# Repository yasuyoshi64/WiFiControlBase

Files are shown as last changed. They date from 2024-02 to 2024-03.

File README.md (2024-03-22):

# sdkconfig
Serial flasher config

	Flash size				4MB

Partition Table

	Patition Table			Single factory app (large), no OTA

WiFiControlBase

	LED GPIO number			5

SD card PIN configuration

	MOSI GPIO number		17
	MOSO GPIO number		19
	CLK GPIO number			18
	CS GPIO number			16
	SD card sw GPIO number	4

OLED(SSD1306) PIN configuration

	I2C SDA GPIO number		21
	I2C SCL GPIO number		22

HTTP Server

	WebSocket server support	TRUE

FAT Filesystem support

	Long filename support	Long filename buffer in heap
	OEM Code Page			Japanese (DBCS) (CP932)

Color settings

	Color depth.			1: 1 byte per pixel

Font usage

Enable built-in fonts

	Enable UNSCII 8 (Perfect monospace font)	TRUE

3rd Party Libraries

	QR code library			TRUE

# 機能

## SDカードの内容

### ./config

```
ssid=[Wi-Fi SSID]
pass=[Wi-Fi Password]
```

### ./document

ここにはWeb用のファイルを格納します。

## 使い方

* 「No file」と表示されている場合はSDカードを挿入します。
* 「Wi-Fi Connecting」はWi-Fi接続中です。
* Wi-Fi接続完了後はQRコードが表示されます。QRコードを読み込むとWebのURLが読み込まれ、documentのWebが表示されます。
* QRコードは30秒で消灯します。GPIO0のボタンを押下すると再度30秒表示されます。
* SDカードは電源ON中でも抜き差し可能です。

## 回路図

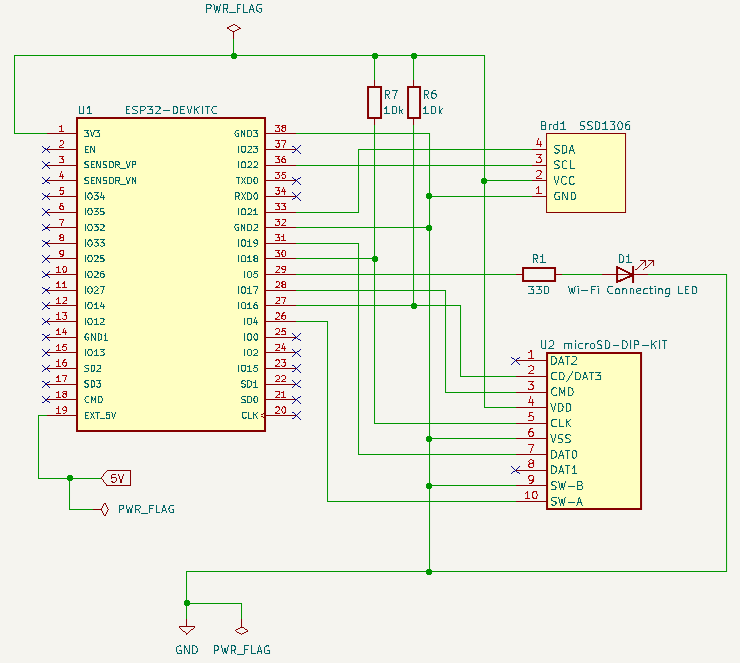
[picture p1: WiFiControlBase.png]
回路図


## Web画面

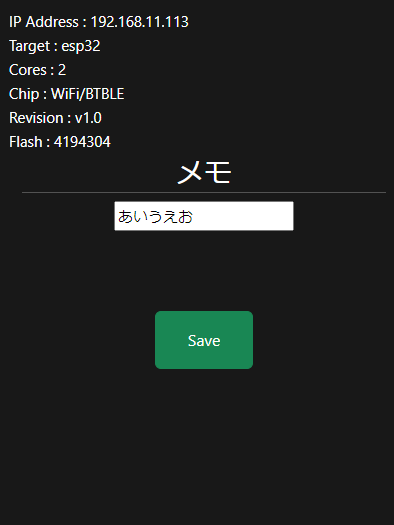
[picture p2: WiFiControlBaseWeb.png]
Web画面


ロード時にIPアドレスやチップ情報などを読み込み。
メモを入力してSaveボタンをクリックするとSDカードのsaveファイルに格納されます。
メモは再ロード時に読み込まれます。

# _Sample project_

(See the README.md file in the upper level 'examples' directory for more information about examples.)

This is the simplest buildable example. The example is used by command `idf.py create-project`
that copies the project to user specified path and set it's name. For more information follow the [docs page](https://docs.espressif.com/projects/esp-idf/en/latest/api-guides/build-system.html#start-a-new-project)

## How to use example
We encourage the users to use the example as a template for the new projects.
A recommended way is to follow the instructions on a [docs page](https://docs.espressif.com/projects/esp-idf/en/latest/api-guides/build-system.html#start-a-new-project).

## Example folder contents

The project **sample_project** contains one source file in C language [main.c](main/main.c). The file is located in folder [main](main).

ESP-IDF projects are built using CMake. The project build configuration is contained in `CMakeLists.txt`
files that provide set of directives and instructions describing the project's source files and targets
(executable, library, or both). 

Below is short explanation of remaining files in the project folder.

```
├── CMakeLists.txt
├── main
│   ├── CMakeLists.txt
│   └── main.c
└── README.md                  This is the file you are currently reading
```
Additionally, the sample project contains Makefile and component.mk files, used for the legacy Make based build system. 
They are not used or needed when building with CMake and idf.py.

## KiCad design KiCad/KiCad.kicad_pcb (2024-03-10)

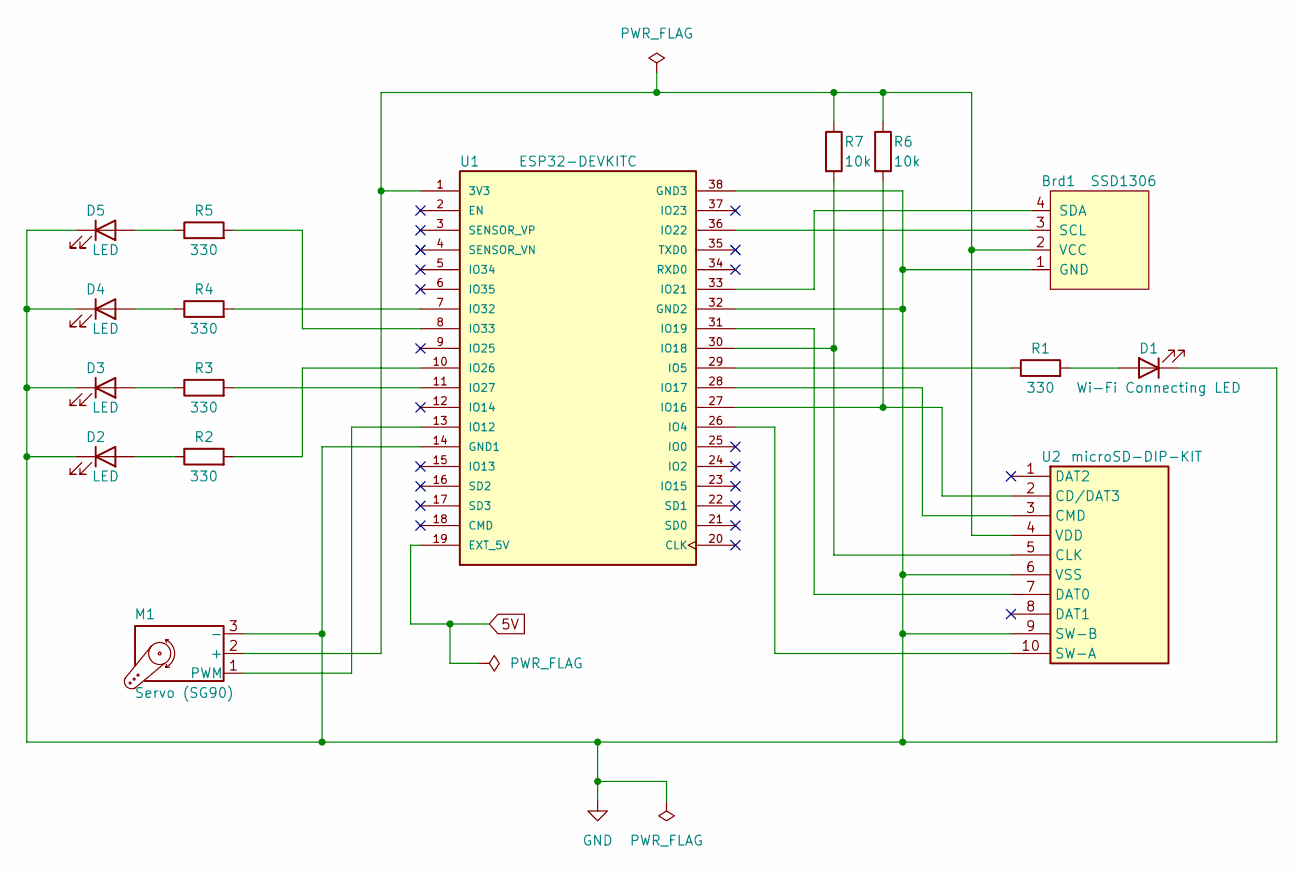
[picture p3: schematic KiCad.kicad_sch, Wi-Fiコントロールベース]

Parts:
Brd1: SSD1306; 128x64OLED
D1: Wi-Fi Connecting LED; LED_D5.0mm
D2, D3, D4, D5: LED; LED_D5.0mm
M1: Servo (SG90); PinHeader_1x03_P2.54mm_Horizontal
R1, R2, R3, R4, R5: 330; R_Axial_DIN0204_L3.6mm_D1.6mm_P5.08mm_Horizontal
R6, R7: 10k; R_Axial_DIN0204_L3.6mm_D1.6mm_P5.08mm_Horizontal
U1: ESP32-DEVKITC; MODULE_ESP32-DEVKITC; PARTREV N/A
U2: microSD-DIP-KIT; microSD-DIP-Kit

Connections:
+3.3V: Brd1.2 (VCC), M1.2 (+), R6.1, R7.1, U1.1 (3V3), U2.4 (VDD)
GND: Brd1.1 (GND), D1.1 (K), D2.1 (K), D3.1 (K), D4.1 (K), D5.1 (K), M1.3 (-), U1.14 (GND1), U1.32 (GND2), U1.38 (GND3), U2.6 (VSS), U2.9 (SW-B)
unnamed: Brd1.3 (SCL), U1.36 (IO22)
unnamed: Brd1.4 (SDA), U1.33 (IO21)
unnamed: D1.2 (A), R1.2
unnamed: D2.2 (A), R2.1
unnamed: D3.2 (A), R3.1
unnamed: D4.2 (A), R4.1
unnamed: D5.2 (A), R5.1
unnamed: M1.1 (PWM), U1.13 (IO12)
unnamed: U1.26 (IO4), U2.10 (SW-A)
unnamed: R1.1, U1.29 (IO5)
unnamed: R6.2, U1.27 (IO16), U2.2 (CD/DAT3)
unnamed: U1.28 (IO17), U2.3 (CMD)
unnamed: R7.2, U1.30 (IO18), U2.5 (CLK)
unnamed: U1.31 (IO19), U2.7 (DAT0)
unnamed: R2.2, U1.10 (IO26)
unnamed: R3.2, U1.11 (IO27)
unnamed: R4.2, U1.7 (IO32)
unnamed: R5.2, U1.8 (IO33)

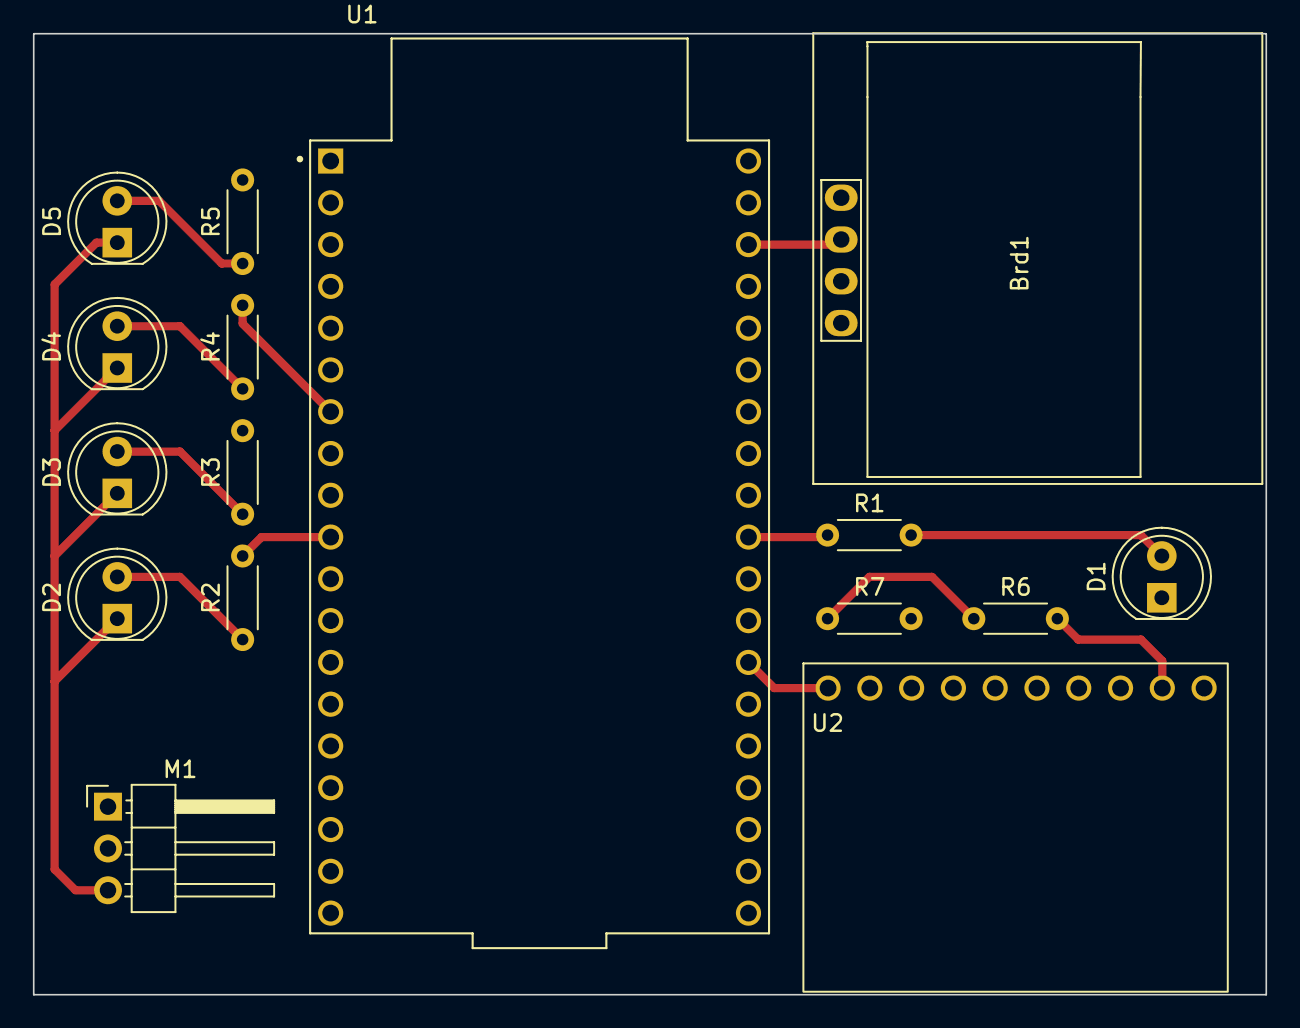
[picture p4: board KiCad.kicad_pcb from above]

Board: 2 copper layers, 74.9 x 58.4 mm, 16 parts (0 on the bottom side), 20 nets.

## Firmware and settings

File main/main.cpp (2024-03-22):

#include <stdio.h>
#include <sys/types.h>
#include <dirent.h>
#include <errno.h>
#include <string.h>
#include <iostream>
#include <map>
#include "freertos/FreeRTOS.h"
#include "freertos/task.h"
#include "freertos/queue.h"
#include "freertos/timers.h"
#include "nvs_flash.h"
#include "driver/gpio.h"
#include "esp_http_server.h"
#include "cJSON.h"
#include "esp_chip_info.h"
#include "esp_flash.h"
#include "esp_log.h"

#include "main.hpp"

#define TAG "Application"
#define ROOT "/mnt"

Application app;

// メッセージ種別 (メッセージキュー用)
enum class AppMessage {
    UpdateDisplay,      // ディスプレイに現在状態表示
    WIFIConnection,     // Wi-Fi接続
    WIFIDisconnection,  // Wi-Fi切断
    Quit                // 終了
};

Application::Application() {
    m_LedState = false;
    m_xHandle = NULL;
    m_xQueue = NULL;
    m_isWiFi = false;
    m_30sec_off = false;
}

// 初期化
void Application::init() {
    ESP_LOGI(TAG, "Init(S)");

    // LED初期化
    gpio_reset_pin((gpio_num_t)CONFIG_LED_PIN);
    gpio_set_direction((gpio_num_t)CONFIG_LED_PIN, GPIO_MODE_OUTPUT);
    led(0);

    // ボタン初期化(GPIO0)
    gpio_reset_pin((gpio_num_t)0);
    gpio_set_intr_type((gpio_num_t)0, GPIO_INTR_NEGEDGE);
    gpio_set_direction((gpio_num_t)0, GPIO_MODE_INPUT);
    gpio_pulldown_dis((gpio_num_t)0);
    gpio_pullup_en((gpio_num_t)0);
    gpio_install_isr_service(0);
    gpio_isr_handler_add((gpio_num_t)0, btn0HandlerFunc, (void*)this);

    // タスク作成
    xTaskCreate(Application::app_task, TAG, configMINIMAL_STACK_SIZE * 2, (void*)this, tskIDLE_PRIORITY, &m_xHandle);

    // メッセージキューの初期化
    m_xQueue = xQueueCreate(10, sizeof(AppMessage));

    // SDカード初期化
    m_sd_card.init(ROOT);
    m_sd_card.setMountCallback(mountFunc, this);

    // 保存データ初期化
    m_save_data.init(ROOT);

    // OLED(SSD1306)ディスプレイ初期化
    m_oled.init(dispInitCompFunc, this);

    // Wi-Fi初期化
    m_wifi.init(wifiConnectFunc, this);

    // Webサーバー初期化
    m_web.init();
    m_web.addHandler(HTTP_GET, "get_data", getData, this);
    m_web.addHandler(HTTP_POST, "set_data", setData, this);
    m_web.addHandler(HTTP_POST, "save", save, this);
    m_web.setWebSocketHandler(sebSocketFunc, this);

    ESP_LOGI(TAG, "Init(E)");
}

// タスク
void Application::app_task(void* arg) {
    Application* pThis = (Application*)arg;
    AppMessage msg;
    bool loop = true;
    while(loop) {
        // メッセージキュー読み取り
        if (pThis->m_xQueue != NULL && xQueueReceive(pThis->m_xQueue, (void*)&msg, portMAX_DELAY) == pdTRUE) {
            switch(msg) {
                case AppMessage::UpdateDisplay:     // ディスプレイに現在状態表示
                    pThis->updateDisplay();
                    break;
                case AppMessage::WIFIConnection:    // Wi-Fi接続
                    pThis->wifiConnection();
                    break;
                case AppMessage::WIFIDisconnection: // Wi-Fi切断
                    pThis->wifiDisconnection();
                    break;
                case AppMessage::Quit:              // 終了
                    loop = false;
                    break;
            }
        }
    }
    // 終了処理
    vTaskDelete(NULL);
}

// LED点灯制御
//  state   : 1=点灯, 0=消灯
void Application::led(int state) {
    m_LedState = state;
    gpio_set_level((gpio_num_t)CONFIG_LED_PIN, m_LedState);
}

// SDカードマウントコールバック
void Application::mountFunc(bool isMount, void* context) {
    ESP_LOGI(TAG, "SD Card mount : %d", isMount);
    Application* pThis = (Application*)context;
    AppMessage msg = AppMessage::UpdateDisplay;
    xQueueSend(pThis->m_xQueue, &msg, portMAX_DELAY);
    if (isMount && pThis->getConfig(ROOT)) {
        AppMessage msg = AppMessage::WIFIConnection;
        xQueueSend(pThis->m_xQueue, &msg, portMAX_DELAY);
    } else {
        AppMessage msg = AppMessage::WIFIDisconnection;
        xQueueSend(pThis->m_xQueue, &msg, portMAX_DELAY);
    }
    // 保存データ読み込み
    pThis->m_save_data.read();
}

// ファイル一覧コールバック
bool Application::fileFunc(bool isFile, const char* name, void* context) {
    Application* pThis = (Application*)context;
    ESP_LOGI(TAG, "%s : %s", isFile ? "File" : "Directory", name);
    return true;
}

// ディスプレイ初期化完了コールバック
void Application::dispInitCompFunc(void* context) {
    Application* pThis = (Application*)context;
    AppMessage msg = AppMessage::UpdateDisplay;
    xQueueSend(pThis->m_xQueue, &msg, portMAX_DELAY);
}

// Wi-Fi接続コールバック
void Application::wifiConnectFunc(bool isConnect, void* context) {
    Application* pThis = (Application*)context;
    if (isConnect) {
        pThis->m_30sec_off = pThis->m_isWiFi = true;
        const char* ipAddress = pThis->m_wifi.getIPAddress();
        ESP_LOGI(TAG, "IP Address: %s", ipAddress);
        pThis->led(0);
        pThis->m_web.start(ipAddress, ROOT);   // Webサーバー開始

        // 30秒後に画面を消灯するためにタイマ設定
        pThis->timer30secStart();

        // pThis->m_sd_card.fileLists("/document/", fileFunc, pThis);
    } else {
        pThis->m_30sec_off = pThis->m_isWiFi = false;
    }
    AppMessage msg = AppMessage::UpdateDisplay;
    xQueueSend(pThis->m_xQueue, &msg, portMAX_DELAY);
}

// 30秒タイマ開始
void Application::timer30secStart() {
    TimerHandle_t xTimer = xTimerCreate(
        "30SecTimer",
        pdMS_TO_TICKS(30000),
        pdFALSE,
        this,
        timer30secFunc
    );
    if (xTimer != NULL)
        xTimerStart(xTimer, 0);
}

// 30秒タイマ
void Application::timer30secFunc(TimerHandle_t xTimer) {
    Application* pThis = (Application*)pvTimerGetTimerID(xTimer);
    if (pThis->m_30sec_off == true) {
        pThis->m_30sec_off = false;
        AppMessage msg = AppMessage::UpdateDisplay;
        xQueueSend(pThis->m_xQueue, &msg, portMAX_DELAY);
    }
}

// 基盤上のボタン押下ハンドラ (GPIO0)
void IRAM_ATTR Application::btn0HandlerFunc(void* context) {
    Application* pThis = (Application*)context;
    pThis->m_30sec_off = true;
    pThis->timer30secStart();
    AppMessage msg = AppMessage::UpdateDisplay;
    xQueueSend(pThis->m_xQueue, &msg, portMAX_DELAY);
}

// ディスプレイに現在状態表示
void Application::updateDisplay() {
    if (!m_oled.isInitialize())
        return;
    if (m_isWiFi) {
        if (m_30sec_off) {
            const char* ipAddress = m_wifi.getIPAddress();
            char url[256];
            sprintf(url, "http://%s/", ipAddress);
            m_oled.dispQRCode(url);
        } else {
            // 画面消灯
            m_oled.dispClear();
        }
    } else if (m_sd_card.isMount()) {
        m_oled.dispString("Wi-Fi Connecting");
        led(1);
    } else {
        m_oled.dispString("No File");
        led(0);
    }
}

// Wi-Fi接続
void Application::wifiConnection() {
    wifiDisconnection();
    if (m_configMap.find("ssid") == m_configMap.end() || m_configMap.find("pass") == m_configMap.end())
        return; // CONFIGファイルにssidまたはpassの設定がない
    const char* ssid = m_configMap["ssid"].c_str();
    const char* pass = m_configMap["pass"].c_str();
    m_wifi.connect(ssid, pass);
}

// Wi-Fi切断
void Application::wifiDisconnection() {
    m_web.stop();
    m_wifi.disconnect();
}

// WebAPI GET /API/get_data
// {
//   "ip_address": "192.168.0.1",
//   "target": "ESP32",
//   "cores": 2,
//   "chip": "WiFi/BT",
//   "revision": "v1.1"
//   "flash": 4,
//   "memo": "abcdefg"
// }
void Application::getData(httpd_req_t *req, void* context) {
    ESP_LOGI(TAG, "getData");
    Application* pThis = (Application*)context;
    char resp[256];
    const char* ip_address = pThis->m_wifi.getIPAddress();
    ip_address = ip_address == NULL ? "" : ip_address;
    esp_chip_info_t chip_info;
    esp_chip_info(&chip_info);
    unsigned major_rev = chip_info.revision / 100;
    unsigned minor_rev = chip_info.revision % 100;
    uint32_t flash_size;
    esp_flash_get_size(NULL, &flash_size);
    const char* memo = pThis->m_save_data.get("memo");
    memo = memo == NULL ? "" : memo;
    std::string format = R"({
        "ip_address": "%s",
        "target": "%s",
        "cores": %d,
        "chip": "%s%s%s%s",
        "revision": "v%d.%d",
        "flash": %d,
        "memo": "%s"
    })";
    sprintf(resp, format.c_str(), 
        ip_address,
        CONFIG_IDF_TARGET,
        chip_info.cores,
        (chip_info.features & CHIP_FEATURE_WIFI_BGN) ? "WiFi/" : "",
        (chip_info.features & CHIP_FEATURE_BT) ? "BT" : "",
        (chip_info.features & CHIP_FEATURE_BLE) ? "BLE" : "",
        (chip_info.features & CHIP_FEATURE_IEEE802154) ? ", 802.15.4 (Zigbee/Thread)" : "",
        major_rev, minor_rev, 
        flash_size,
        memo
    );
    ESP_LOGI(TAG, "%s", resp);
    httpd_resp_set_type(req, "application/json");
    httpd_resp_send(req, resp, strlen(resp));
}

// WebAPI POST /API/set_data
// {
//    memo: "abcdefg"
// }
void Application::setData(httpd_req_t *req, void* context) {
    ESP_LOGI(TAG, "setData");
    Application* pThis = (Application*)context;
    int ret, remaining = req->content_len;
    char body[100];
    if (remaining >= sizeof(body)) {
        ESP_LOGE(TAG, "oversize request body");
        httpd_resp_send_500(req);
        return;
    }
    ret = httpd_req_recv(req, body, remaining);
    if (ret == HTTPD_SOCK_ERR_TIMEOUT) {
        ESP_LOGE(TAG, "timeout");
        httpd_resp_send_408(req);
        return;
    }
    body[ret] = '\0';
    ESP_LOGI(TAG, "body : %s", body);
    cJSON* json = cJSON_Parse(body);
    if (json == NULL) {
        ESP_LOGI(TAG, "json null");
        httpd_resp_send_500(req);
        return;
    }
    cJSON* memo = cJSON_GetObjectItemCaseSensitive(json, "memo");
    if (!cJSON_IsString(memo)) {
        ESP_LOGI(TAG, "json format error");
        httpd_resp_send_500(req);
        return;
    }
    std::string memo_value = cJSON_GetStringValue(memo);
    pThis->m_save_data.set("memo", memo_value.c_str());
    cJSON_Delete(json);
    httpd_resp_send(req, NULL, 0);
}

// WebAPI POST /API/save
void Application::save(httpd_req_t *req, void* context) {
    ESP_LOGI(TAG, "save");
    Application* pThis = (Application*)context;
    pThis->m_save_data.save();
    httpd_resp_send(req, NULL, 0);
}

// WebSocketコールバック
char* Application::sebSocketFunc(const char* data, void* context) {
    return NULL;
}

extern "C" void app_main(void)
{
    nvs_flash_init();     // Flash初期化  (お約束のようなもの)

    app.init();
}

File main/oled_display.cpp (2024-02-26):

/**
 * I2Cに接続されているSSD1306(0.96インチ 128x64 OLEDディスプレイ)のドライブ
 * 
 * 
*/
#include <stdio.h>
#include <string.h>
#include <iostream>
#include "freertos/FreeRTOS.h"
#include "freertos/task.h"
#include "freertos/queue.h"
#include "esp_timer.h"
#include "esp_lcd_panel_io.h"
#include "esp_lcd_panel_ops.h"
#include "driver/i2c.h"
#include "esp_err.h"
#include "esp_log.h"
#include "extra/libs/qrcode/lv_qrcode.h"
#include "oled_display.hpp"

#define TAG "OledDisplay"

#define I2C_HOST        0
#define I2C_HW_ADDR     0x3C
#define I2C_SDA_PIN     CONFIG_SDA_PIN
#define I2C_SCL_PIN     CONFIG_SCL_PIN
#define I2C_OLED_H      128
#define I2C_OLED_V      64

// メッセージ種別 (メッセージキュー用)
enum class OledDisplayMessage {
    Init,       // 画面初期処理
    Clear,      // 画面消去
    On,         // 画面On
    Off,        // 画面Off
    QRCode,     // QRコード表示
    String,     // 文字列表示
    Quit        // 終了
};

OledDisplay::OledDisplay() {
    clear();
}

void OledDisplay::clear() {
    m_funcInitilizationComplettion = NULL;
    m_hDisp = NULL;
    m_panel_handle = NULL;
    m_xHandle = NULL;
    m_xQueue = NULL;
    m_text = "";
}

void OledDisplay::init(CallbackInitializationCompletionFunction func, void* context) {
    ESP_LOGI(TAG, "Init(S)");

    m_funcInitilizationComplettion = func;
    m_funcInitilizationComplettionContext = context;

    // タスク作成
    xTaskCreate(OledDisplay::task, TAG, configMINIMAL_STACK_SIZE * 3, (void*)this, tskIDLE_PRIORITY, &m_xHandle);

    // メッセージキューの初期化
    m_xQueue = xQueueCreate(10, sizeof(OledDisplayMessage));

    // 初期化用メッセージポスト
    OledDisplayMessage msg = OledDisplayMessage::Init;
    xQueueSend(m_xQueue, &msg, portMAX_DELAY);

   ESP_LOGI(TAG, "Init(E)");
}

// タスク
void OledDisplay::task(void* arg) {
    OledDisplay* pThis = (OledDisplay*)arg;
    OledDisplayMessage msg;
    bool loop = true;
    while(loop) {
        // メッセージキュー読み取り
        if (pThis->m_xQueue != NULL && xQueueReceive(pThis->m_xQueue, (void*)&msg, portMAX_DELAY) == pdTRUE) {
            switch(msg) {
                case OledDisplayMessage::Init:      // 画面初期化処理
                    pThis->initDisplay();
                    break;
                case OledDisplayMessage::Clear:     // 画面消去
                    lv_obj_clean(lv_scr_act());
                    break;
                case OledDisplayMessage::On:        // 画面On
                    esp_lcd_panel_disp_on_off(pThis->m_panel_handle, true);     // LCDのON/OFF  ONにする
                    break;
                case OledDisplayMessage::Off:       // 画面Off
                    esp_lcd_panel_disp_on_off(pThis->m_panel_handle, false);    // LCDのON/OFF  OFFにする
                    break;
                case OledDisplayMessage::QRCode:    // QRコード表示
                    {
                        lv_obj_t* active_screen = lv_scr_act();
                        lv_obj_clean(active_screen);
                        lv_obj_t *qr = lv_qrcode_create(active_screen, 64, lv_color_hex3(0xFF), lv_color_hex3(0x00));
                        lv_qrcode_update(qr, pThis->m_text.c_str(), pThis->m_text.size());
                        lv_obj_center(qr);
                    }
                    break;
                case OledDisplayMessage::String:    // 文字列表示
                    {
                        lv_obj_t* active_screen = lv_scr_act();
                        lv_obj_clean(active_screen);
                        lv_obj_t *label = lv_label_create(active_screen);
                        lv_label_set_text(label, pThis->m_text.c_str());
                        lv_obj_center(label);
                    }
                    break;
                case OledDisplayMessage::Quit:      // 終了
                    loop = false;
                    break;
            }
        }
    }
    // 終了処理
    pThis->clear();
    vTaskDelete(NULL);
}

// 表示内容をクリア
void OledDisplay::dispClear() {
    ESP_LOGI(TAG, "dispClear");
    OledDisplayMessage msg = OledDisplayMessage::Clear;
    xQueueSend(m_xQueue, &msg, portMAX_DELAY);
}

// ディスプレイON
void OledDisplay::dispOn() {
    ESP_LOGI(TAG, "dispOn");
    OledDisplayMessage msg = OledDisplayMessage::On;
    xQueueSend(m_xQueue, &msg, portMAX_DELAY);
}

// ディスプレイOFF
void OledDisplay::dispOff() {
    ESP_LOGI(TAG, "dispOff");
    OledDisplayMessage msg = OledDisplayMessage::Off;
    xQueueSend(m_xQueue, &msg, portMAX_DELAY);
}

// QRコード表示
void OledDisplay::dispQRCode(const char* text) {
    ESP_LOGI(TAG, "dispQRCode");
    m_text = text;
    OledDisplayMessage msg = OledDisplayMessage::QRCode;
    xQueueSend(m_xQueue, &msg, portMAX_DELAY);
}

// 文字列表示
void OledDisplay::dispString(const char* text) {
    ESP_LOGI(TAG, "dispString");
    m_text = text;
    OledDisplayMessage msg = OledDisplayMessage::String;
    xQueueSend(m_xQueue, &msg, portMAX_DELAY);
}
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

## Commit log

2024-02-26 初期コミット
2024-02-26 web読み込み時にsdカードのdocumentフォルダ直下のhtmlファイル読みに行くように修正。
2024-03-02 4つのLEDを操作できるようにWebAPIを追加
2024-03-10 サーボを操作できるWebAPI & WebSocketを追加
    ・サーボを操作できるWebAPI & WebSocketを追加
    ・KiCadの回路図を追加
    [WiFiControlBase.kicad_pcb, WiFiControlBase.kicad_sch]
2024-03-10 少し説明追加
2024-03-11 トリム値の保存機能を追加
2024-03-11 電源ON時にサーボトリム値読み込み
2024-03-11 フロント(Vue3)を追加
2024-03-11 KiCadのファイル名変更
    [KiCad.kicad_pcb, KiCad.kicad_sch]
2024-03-22 余計なものを削除
    [KiCad.kicad_sch]
2024-03-22 説明を追加
